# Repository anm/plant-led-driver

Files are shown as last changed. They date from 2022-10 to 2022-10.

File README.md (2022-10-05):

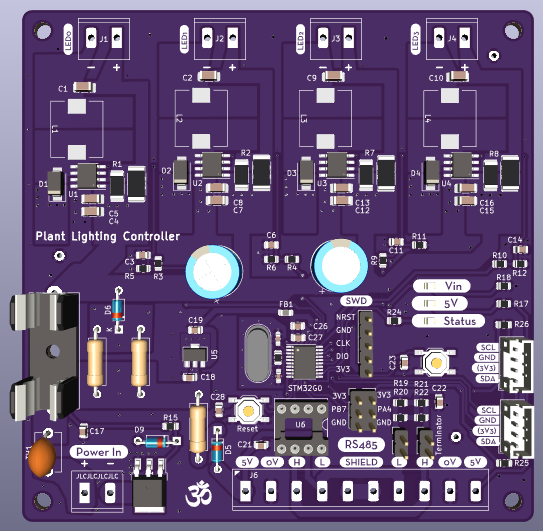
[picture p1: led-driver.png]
Board front render


This was designed for grow light but obviously can be rather more general
purpose. I have made one and it works.

Drivers are PAM2863, controller STM32G030F6P6.

Software incomplete, but may clean up / publish at some point, especially if
there is interest. I didn't do modbus yet but the 485 link works with custom
commands. It could also be persuaded to understand DMX, I believe.

Some idiosyncracities in design becasue of what parts I had. The 5V supply is
just for the MAX485. You could use a MAX3485 or other 3.3V part. The board is
<100x100mm for cheap manufacture, and the components are cheap from LCSC. The
throughhole stuff could be made SMD for cheap manufacture, but I made this for
assembling myself with parts I had.

The electrolytic caps and inrush NTC are not needed.

I designed it for, and tested it up to, 700mA (nominal) per channel. The
drivers can do 2A, and the specified components should also work at 2A, except
that you need to change the current sense resistor to change the maximum
current. Choose resistance according to the table in the datasheet or on the
back of the board, with sufficient power dissapation.

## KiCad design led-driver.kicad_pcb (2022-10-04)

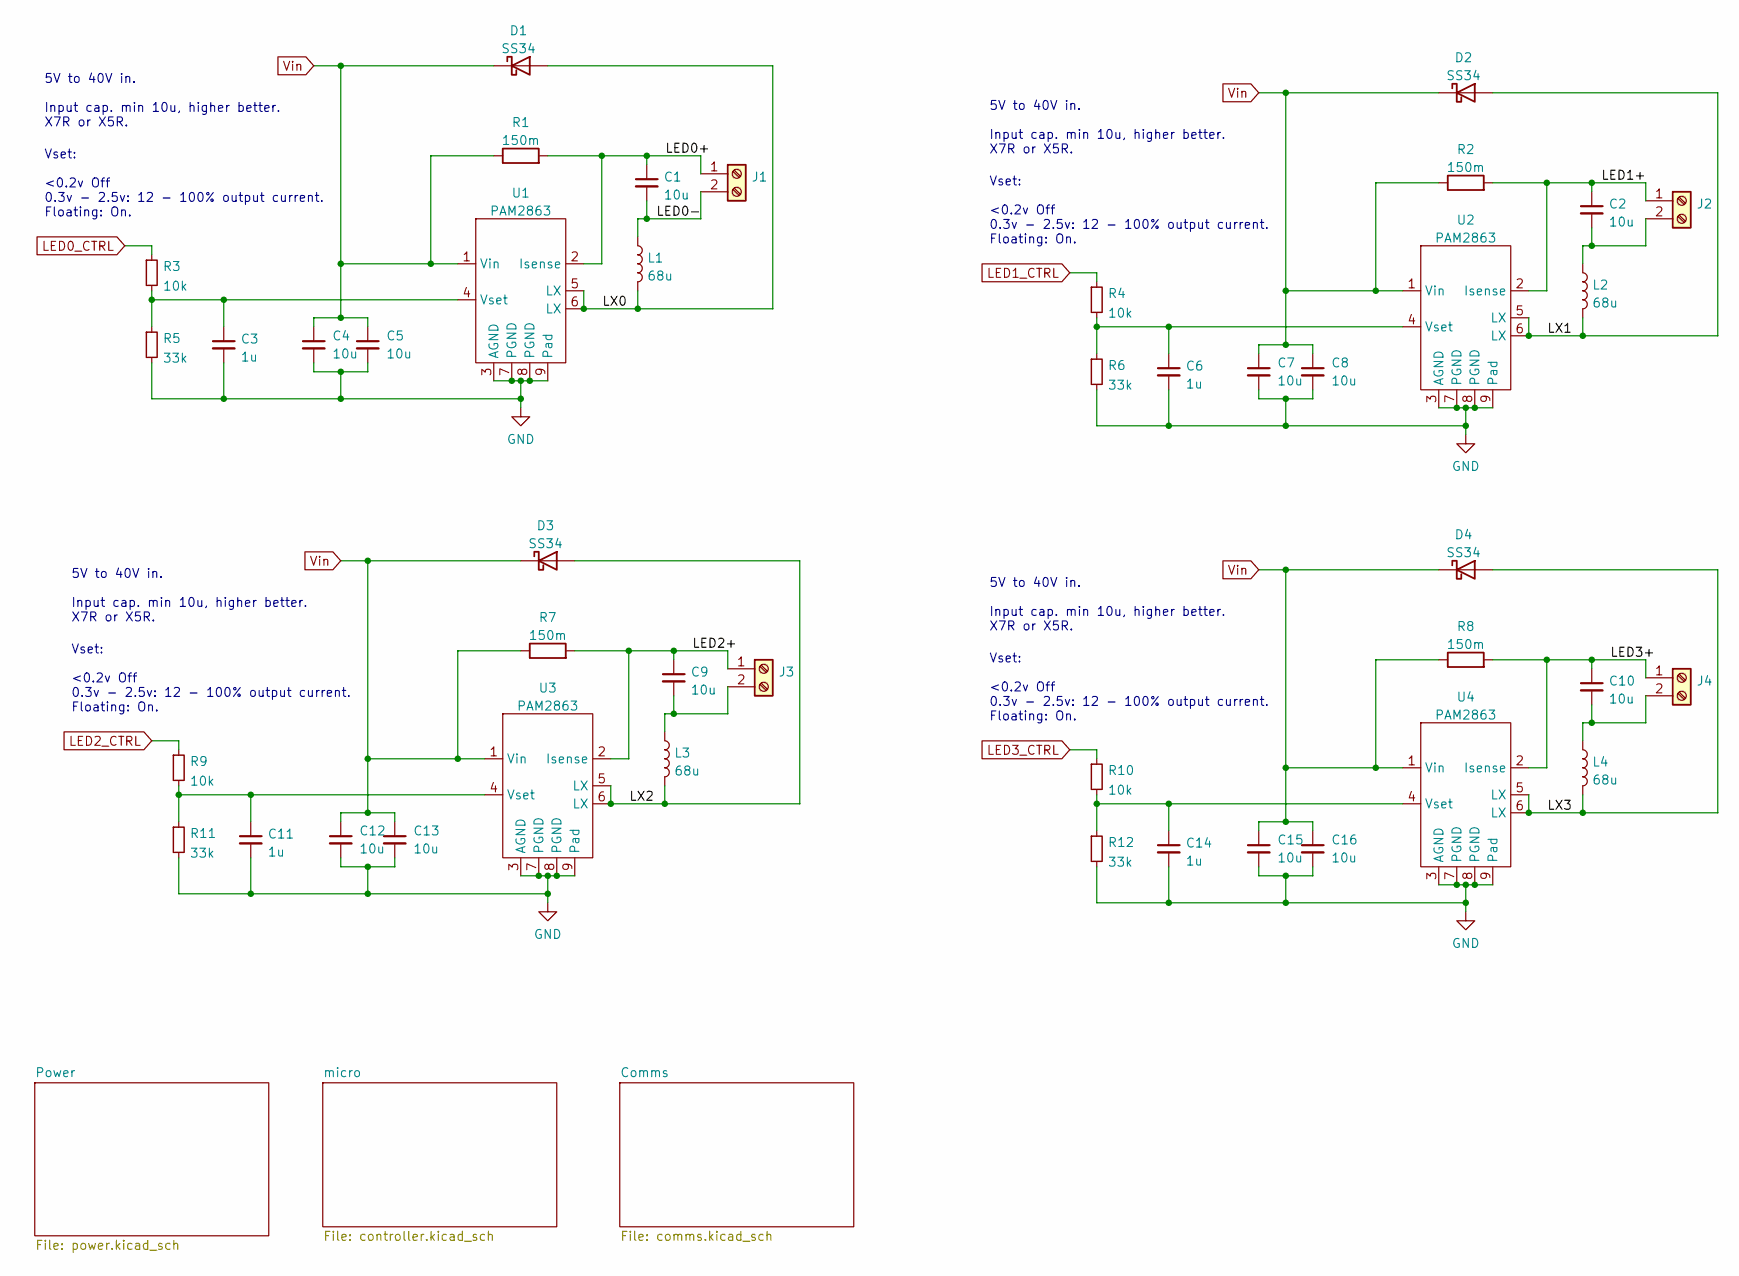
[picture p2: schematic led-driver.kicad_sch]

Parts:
C1, C2, C4, C5, C7, C8, C9, C10, C12, C13, C15, C16: 10u; C_1206_3216Metric_Pad1.33x1.80mm_HandSolder; LCSC# C89632
C3, C6, C11, C14: 1u; C_0805_2012Metric
D1, D2, D3, D4: SS34; D_SMA; Part# Slkor SS34; LCSC# C408258
J1, J2, J3, J4: TerminalBlock_KEFENG_Blue_2
L1, L2, L3, L4: 68u; Inductor_SMD_10.2x11.0x5; LCSC# C2837473
R1, R2, R7, R8: 150m; R_2010_5025Metric_Pad1.40x2.65mm_HandSolder; LCSC# C382266
R3, R4, R9, R10: 10k; R_0805_2012Metric
R5, R6, R11, R12: 33k; R_0805_2012Metric
U1, U2, U3, U4: PAM2863; HSOP-8-1EP_3.9x4.9mm_P1.27mm_EP2.41x3.1mm_ThermalVias_0.3mm

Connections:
/LED0+: C1.1, J1.1, R1.2, U1.2 (Isense)
/LED0-: C1.2, J1.2, L1.1
/LED1+: C2.1, J2.1, R2.2, U2.2 (Isense)
/LED2+: C9.1, J3.1, R7.2, U3.2 (Isense)
/LED3+: C10.1, J4.1, R8.2, U4.2 (Isense)
/LX0: D1.2 (A), L1.2, U1.5 (LX), U1.6 (LX)
/LX1: D2.2 (A), L2.2, U2.5 (LX), U2.6 (LX)
/LX2: D3.2 (A), L3.2, U3.5 (LX), U3.6 (LX)
/LX3: D4.2 (A), L4.2, U4.5 (LX), U4.6 (LX)
GND: C3.2, C4.2, C5.2, C6.2, C7.2, C8.2, C11.2, C12.2, C13.2, C14.2, C15.2, C16.2, R5.2, R6.2, R11.2, R12.2, U1.3 (AGND), U1.7 (PGND), U1.8 (PGND), U1.9 (Pad), U2.3 (AGND), U2.7 (PGND), U2.8 (PGND), U2.9 (Pad), U3.3 (AGND), U3.7 (PGND), U3.8 (PGND), U3.9 (Pad), U4.3 (AGND), U4.7 (PGND), U4.8 (PGND), U4.9 (Pad); also elsewhere on the board
LED0_CTRL: R3.1; also elsewhere on the board
LED1_CTRL: R4.1; also elsewhere on the board
LED2_CTRL: R9.1; also elsewhere on the board
LED3_CTRL: R10.1; also elsewhere on the board
unnamed: C2.2, J2.2, L2.1
unnamed: C3.1, R3.2, R5.1, U1.4 (Vset)
unnamed: C6.1, R4.2, R6.1, U2.4 (Vset)
unnamed: C9.2, J3.2, L3.1
unnamed: C10.2, J4.2, L4.1
unnamed: C11.1, R9.2, R11.1, U3.4 (Vset)
unnamed: C14.1, R10.2, R12.1, U4.4 (Vset)
Vin: C4.1, C5.1, C7.1, C8.1, C12.1, C13.1, C15.1, C16.1, D1.1 (K), D2.1 (K), D3.1 (K), D4.1 (K), R1.1, R2.1, R7.1, R8.1, U1.1 (Vin), U2.1 (Vin), U3.1 (Vin), U4.1 (Vin); also elsewhere on the board

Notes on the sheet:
Vset: <0.2v Off 0.3v - 2.5v: 12 - 100% output current. Floating: On.
5V to 40V in. Input cap. min 10u, higher better. X7R or X5R.

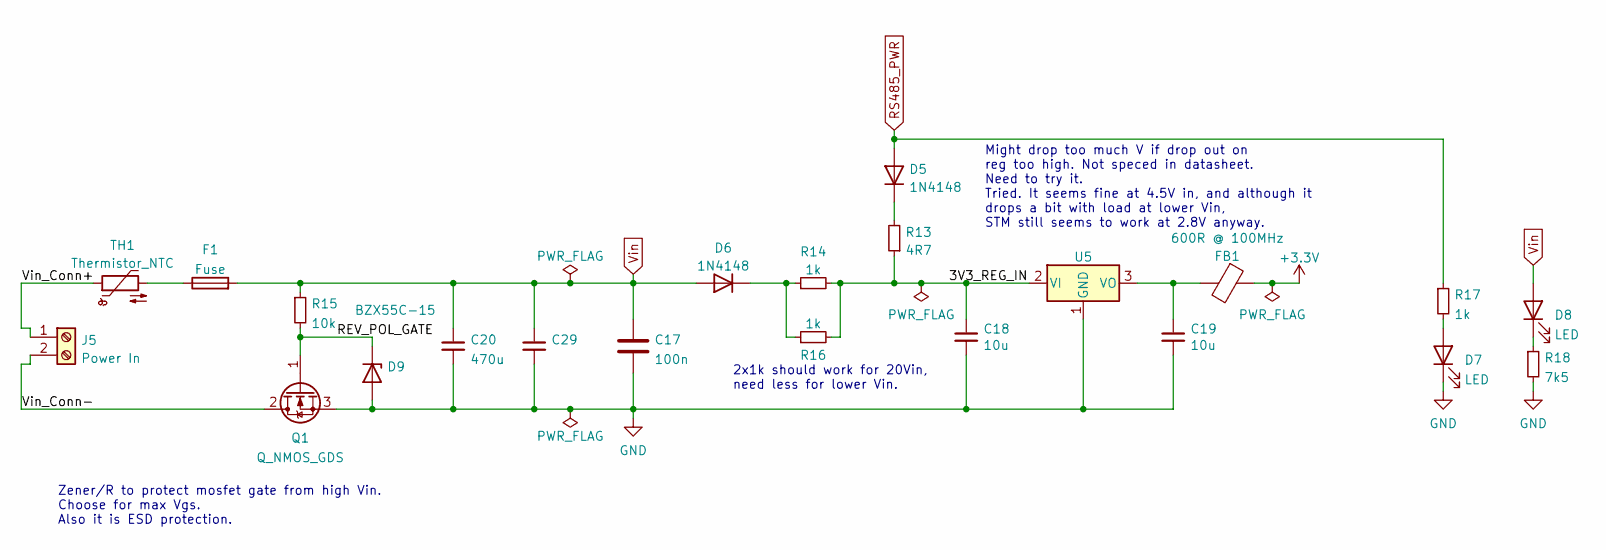
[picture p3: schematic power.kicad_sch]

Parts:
C17: 100n; C_0805_2012Metric
C18, C19: 10u; C_0805_2012Metric; Part# CL21A106KAYNNNE; LCSC# C15850
C20: 470u; CP_Radial_D10.0mm_P5.00mm
C29: CP_Radial_D10.0mm_P5.00mm
D5, D6: 1N4148; D_DO-35_SOD27_P7.62mm_Horizontal
D7, D8: LED; LED_0805_2012Metric
D9: BZX55C-15; D_DO-35_SOD27_P7.62mm_Horizontal
F1: Fuse; Fuseholder_Cylinder-5x20mm_Schurter_0031_8201_Horizontal_Op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
FB1: 600R @ 100MHz; L_0805_2012Metric; Part# GZ2012D601TF; LCSC# C1017
J5: Power In; TerminalBlock_KEFENG_Blue_2
Q1: Q_NMOS_GDS; TO-252-3_TabPin2; Part Overspecced but I have some NVD5865NL
R13: 4R7; R_Axial_DIN0309_L9.0mm_D3.2mm_P12.70mm_Horizontal
R14, R16: 1k; R_Axial_DIN0309_L9.0mm_D3.2mm_P12.70mm_Horizontal
R15: 10k; R_0805_2012Metric_Pad1.20x1.40mm_HandSolder
R17: 1k; R_0805_2012Metric
R18: 7k5; R_0805_2012Metric
TH1: Thermistor_NTC; C_Disc_D7.5mm_W5.0mm_P7.50mm
U5: UMW_HT7533-1_3.3V_High-In_LDO_SOT89; SOT-89-3

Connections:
+3V3: FB1.1; also elsewhere on the board
/Power/3V3_REG_IN: C18.1, R13.1, R14.2, R16.2, U5.2 (VI)
/Power/REV_POL_GATE: D9.1 (K), Q1.1 (G), R15.2
/Power/Vin_Conn+: J5.1, TH1.1
/Power/Vin_Conn-: J5.2, Q1.2 (D)
GND: C17.2, C18.2, C19.2, C20.2, C29.2, D7.1 (K), D9.2 (A), Q1.3 (S), R18.2, U5.1 (GND); also elsewhere on the board
unnamed: C19.1, FB1.2, U5.3 (VO)
unnamed: D5.1 (K), R13.2
unnamed: D6.1 (K), R14.1, R16.1
unnamed: D7.2 (A), R17.2
unnamed: D8.1 (K), R18.1
unnamed: F1.1, TH1.2
RS485_PWR: D5.2 (A), R17.1; also elsewhere on the board
Vin: C17.1, C20.1, C29.1, D6.2 (A), D8.2 (A), F1.2, R15.1; also elsewhere on the board

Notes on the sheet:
Might drop too much V if drop out on reg too high. Not speced in datasheet. Need to try it. Tried. It seems fine at 4.5V in, and although it drops a bit with load at lower Vin, STM still seems to work at 2.8V anyway.
2x1k should work for 20Vin, need less for lower Vin.
Zener/R to protect mosfet gate from high Vin. Choose for max Vgs. Also it is ESD protection.

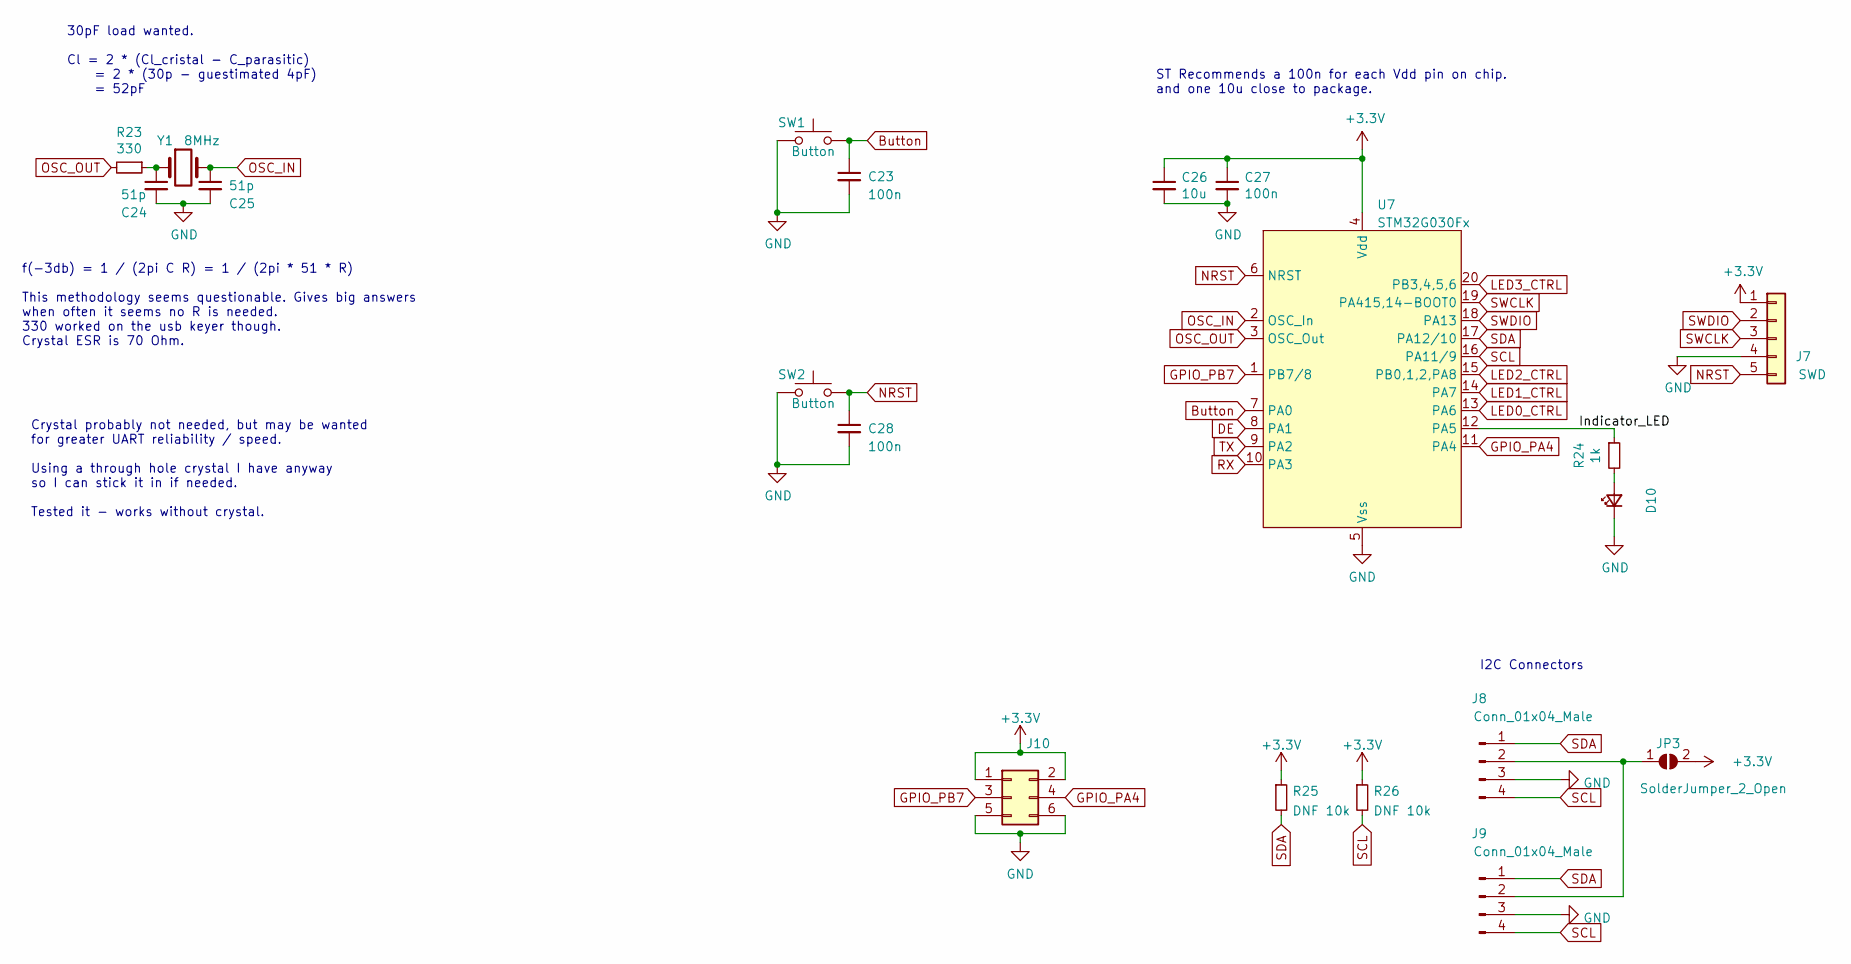
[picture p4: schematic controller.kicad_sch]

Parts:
C23, C27, C28: 100n; C_0805_2012Metric; Part# CL05B104KO5NNNC; LCSC# C1525
C24, C25: 51p; C_0603_1608Metric_Pad1.08x0.95mm_HandSolder
C26: 10u; C_0805_2012Metric; Part# CL21A106KAYNNNE; LCSC# C15850
D10: LED_0805_2012Metric; LCSC# C2297
J7: SWD; PinHeader_1x05_P2.54mm_Vertical
J8, J9: Conn_01x04_Male; JST_PH_B4B-PH-K_1x04_P2.00mm_Vertical
J10: Conn_02x03_Counter_Clockwise; PinHeader_2x03_P2.54mm_Vertical
JP3: SolderJumper_2_Open; SolderJumper-2_P1.3mm_Open_TrianglePad1.0x1.5mm
R23: 330; R_0805_2012Metric; LCSC# C17630
R24: 1k; R_0805_2012Metric; LCSC# C17590
R25, R26: DNF 10k; R_0805_2012Metric_Pad1.20x1.40mm_HandSolder
SW1, SW2: Button; SW_SPST_TL3342; LCSC# C412369
U7: STM32G030Fx; TSSOP-20_4.4x6.5mm_P0.65mm
Y1: 8MHz; Crystal_HC49-4H_Vertical

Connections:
+3V3: C26.1, C27.1, J7.1, J10.1, J10.2, JP3.2 (B), R25.1, R26.1, U7.4 (Vdd); also elsewhere on the board
/micro/Indicator_LED: R24.1, U7.12 (PA5)
Button: C23.1, SW1.2, U7.7 (PA0)
DE: U7.8 (PA1); also elsewhere on the board
GND: C23.2, C24.2, C25.2, C26.2, C27.2, C28.2, D10.1 (K), J7.4, J8.3, J9.3, J10.5, J10.6, SW1.1, SW2.1, U7.5 (Vss); also elsewhere on the board
GPIO_PA4: J10.4, U7.11 (PA4)
GPIO_PB7: J10.3, U7.1 (PB7/8)
LED0_CTRL: U7.13 (PA6); also elsewhere on the board
LED1_CTRL: U7.14 (PA7); also elsewhere on the board
LED2_CTRL: U7.15 (PB0,1,2,PA8); also elsewhere on the board
LED3_CTRL: U7.20 (PB3,4,5,6); also elsewhere on the board
NRST: C28.1, J7.5, SW2.2, U7.6 (NRST)
unnamed: C24.1, R23.1, Y1.1
unnamed: D10.2 (A), R24.2
unnamed: J8.2, J9.2, JP3.1 (A)
OSC_IN: C25.1, U7.2 (OSC_In), Y1.2
OSC_OUT: R23.2, U7.3 (OSC_Out)
RX: U7.10 (PA3); also elsewhere on the board
SCL: J8.4, J9.4, R26.2, U7.16 (PA11/9)
SDA: J8.1, J9.1, R25.2, U7.17 (PA12/10)
SWCLK: J7.3, U7.19 (PA415,14-BOOT0)
SWDIO: J7.2, U7.18 (PA13)
TX: U7.9 (PA2); also elsewhere on the board

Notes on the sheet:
ST Recommends a 100n for each Vdd pin on chip. and one 10u close to package.
30pF load wanted. Cl = 2 * (Cl_cristal - C_parasitic) = 2 * (30p - guestimated 4pF) = 52pF
I2C Connectors
Crystal probably not needed, but may be wanted for greater UART reliability / speed. Using a through hole crystal I have anyway so I can stick it in if needed. Tested it - works without crystal.
f(-3db) = 1 / (2pi C R) = 1 / (2pi * 51 * R) This methodology seems questionable. Gives big answers when often it seems no R is needed. 330 worked on the usb keyer though. Crystal ESR is 70 Ohm.

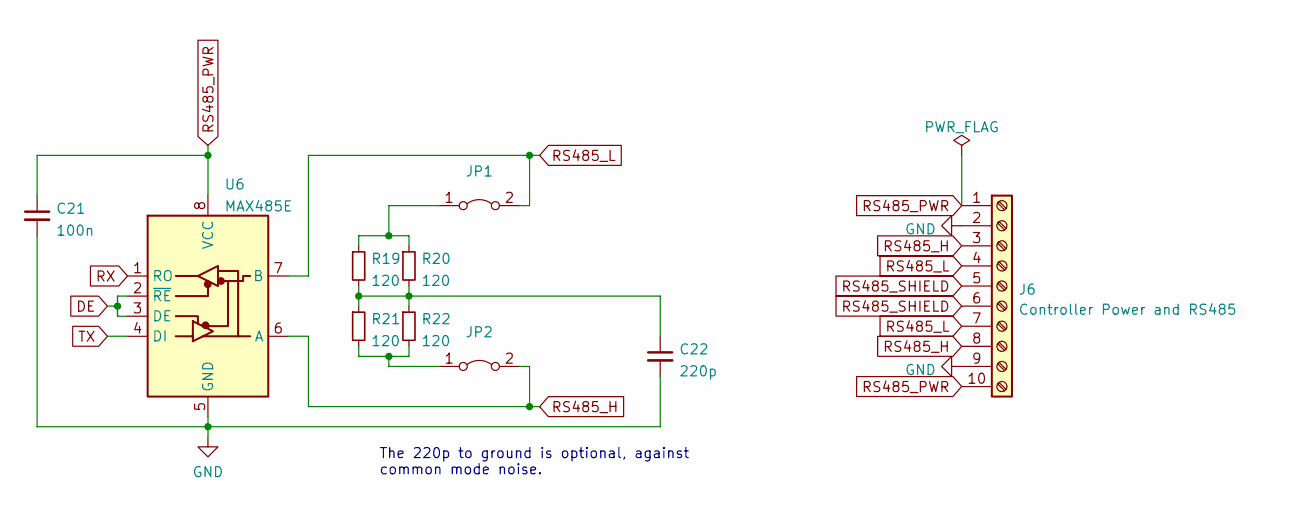
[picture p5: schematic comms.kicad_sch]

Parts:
C21: 100n; C_0805_2012Metric
C22: 220p; C_0805_2012Metric
J6: Controller Power and RS485; TerminalBlock_KEFENG_Blue_10
JP1, JP2: PinHeader_1x02_P2.54mm_Vertical
R19, R20, R21, R22: 120; R_0805_2012Metric
U6: MAX485E; DIP-8_W7.62mm_Socket

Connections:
DE: U6.2 (~RE), U6.3 (DE); also elsewhere on the board
GND: C21.2, C22.2, J6.2, J6.9, U6.5 (GND); also elsewhere on the board
unnamed: C22.1, R19.2, R20.2, R21.1, R22.1
unnamed: JP1.1 (A), R19.1, R20.1
unnamed: JP2.1 (A), R21.2, R22.2
RS485_H: J6.3, J6.8, JP2.2 (B), U6.6 (A)
RS485_L: J6.4, J6.7, JP1.2 (B), U6.7 (B)
RS485_PWR: C21.1, J6.1, J6.10, U6.8 (VCC); also elsewhere on the board
RS485_SHIELD: J6.5, J6.6
RX: U6.1 (RO); also elsewhere on the board
TX: U6.4 (DI); also elsewhere on the board

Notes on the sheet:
The 220p to ground is optional, against common mode noise.

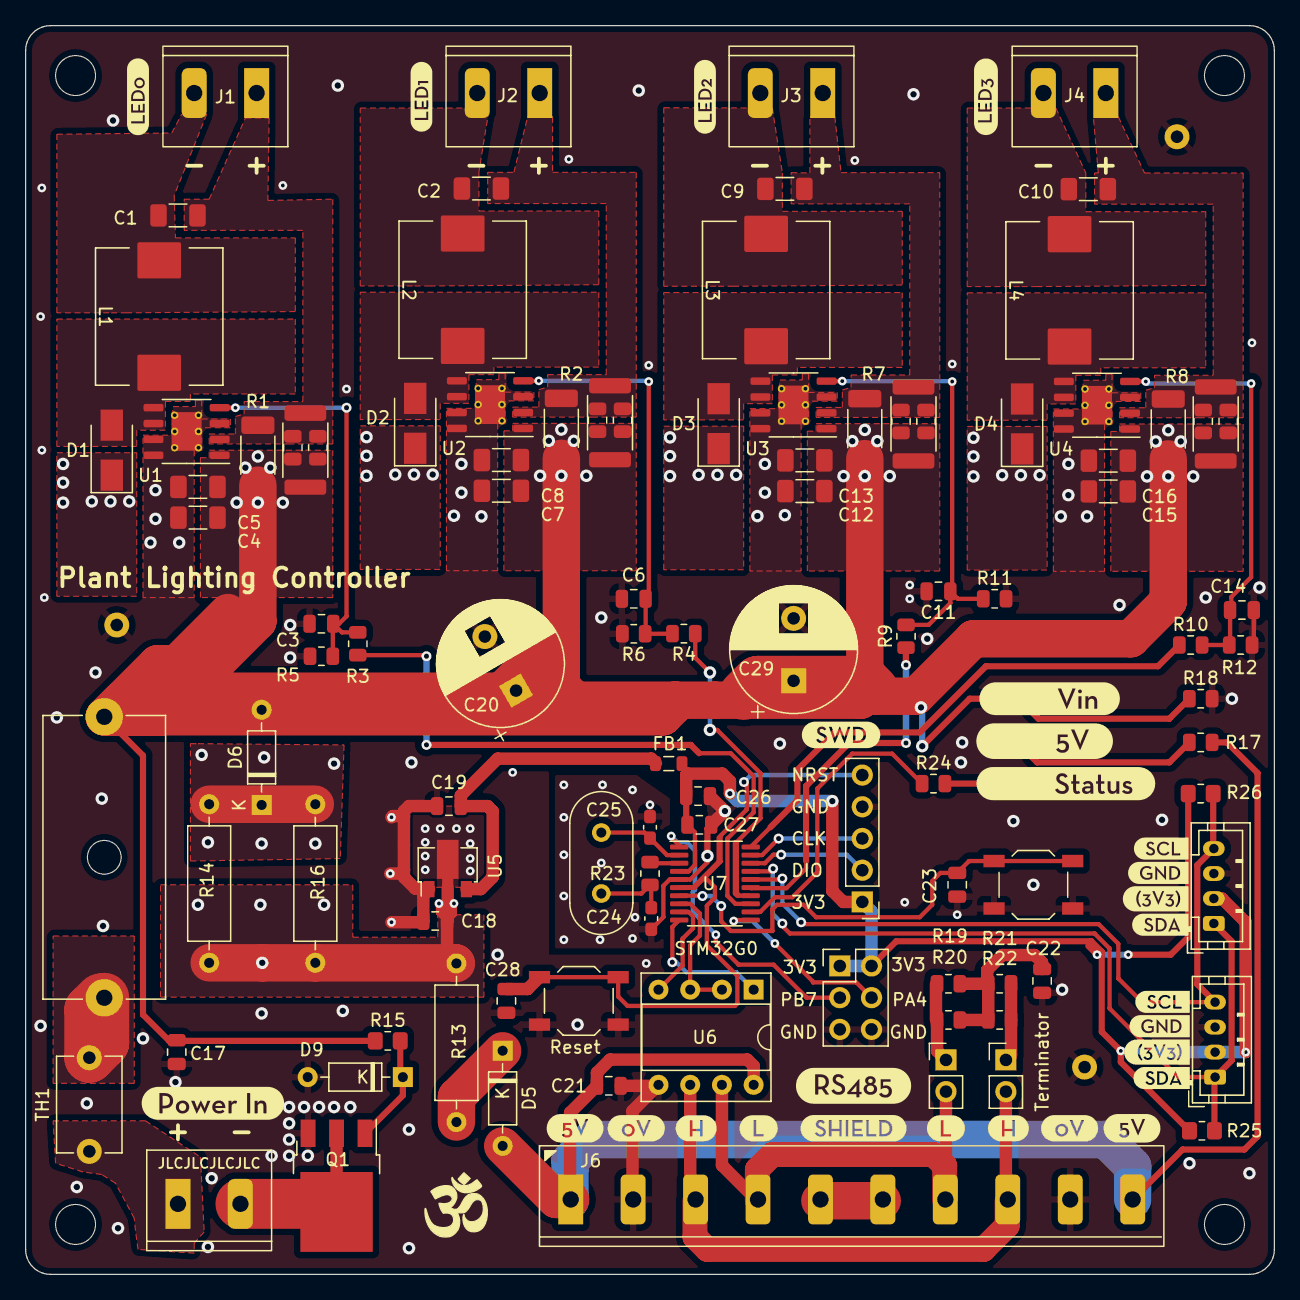
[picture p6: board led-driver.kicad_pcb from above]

Board: 2 copper layers, 100.0 x 100.0 mm, 123 parts (1 on the bottom side), 57 nets.

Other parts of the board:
kibuzzard-633CB0FB: G***; kibuzzard-633CB0FB
kibuzzard-6276EDEB: G***; kibuzzard-6276EDEB
kibuzzard-6276EF20: G***; kibuzzard-6276EF20
kibuzzard-6276EF29: G***; kibuzzard-6276EF29
kibuzzard-6276EF30: G***; kibuzzard-6276EF30
kibuzzard-62758A42: G***; kibuzzard-62758A42
kibuzzard-62769A2B, kibuzzard-62769A2B#2: G***; kibuzzard-62769A2B
kibuzzard-62770F6E: G***; kibuzzard-62770F6E
kibuzzard-627614DF: G***; kibuzzard-627614DF
kibuzzard-627692FB, kibuzzard-627692FB#2: G***; kibuzzard-627692FB
kibuzzard-6275894F, kibuzzard-6275894F#2: G***; kibuzzard-6275894F
kibuzzard-6275896E, kibuzzard-6275896E#2: G***; kibuzzard-6275896E
kibuzzard-62758962, kibuzzard-62758962#2: G***; kibuzzard-62758962
kibuzzard-62758977, kibuzzard-62758977#2: G***; kibuzzard-62758977
kibuzzard-62758985: G***; kibuzzard-62758985
kibuzzard-62761502: G***; kibuzzard-62761502
kibuzzard-62761516: G***; kibuzzard-62761516
kibuzzard-62769306, kibuzzard-62769306#2: G***; kibuzzard-62769306
kibuzzard-62769315, kibuzzard-62769315#2: G***; kibuzzard-62769315

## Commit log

2022-10-04 v0.2 WIP: Original as manufatured (v0.1) with larger ground vias connected and added labels.
    [comms.kicad_sch, connectors.kicad_sch, controller.kicad_sch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]
2022-10-04 Added board front render.
2022-10-05 Schematic cleanup and readme improvement.
    [comms.kicad_sch, controller.kicad_sch, led-driver.kicad_sch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]
